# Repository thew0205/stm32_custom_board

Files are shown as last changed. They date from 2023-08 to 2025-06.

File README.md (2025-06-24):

# 🛠️ Custom STM32 Development Board

This project involves the design and fabrication of a **custom STM32 development board** based on the powerful **STM32F103C8T6** ARM Cortex-M3 microcontroller.

---

## 📷 Project Images

<div align="center">
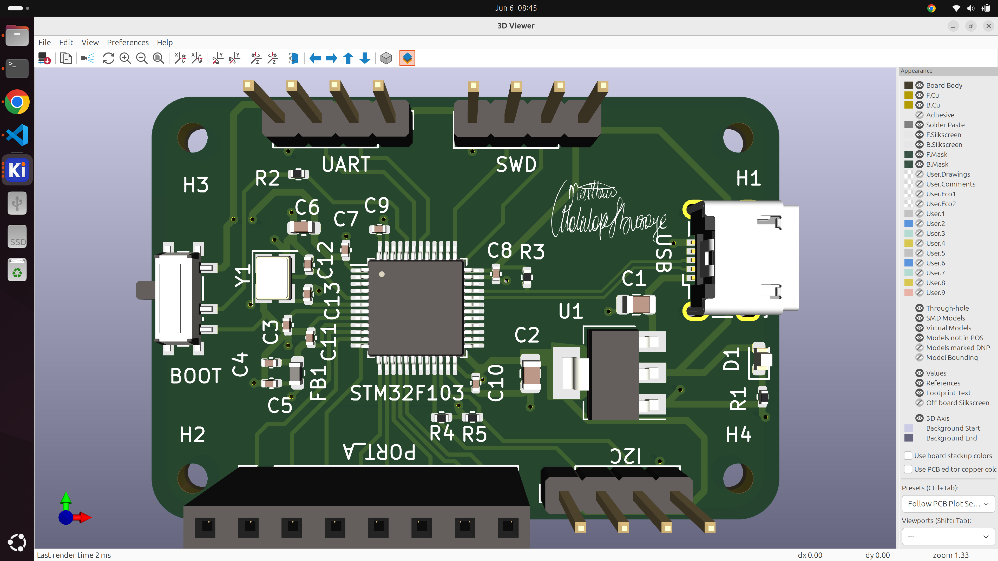
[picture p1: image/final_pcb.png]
Final PCB Layout
  
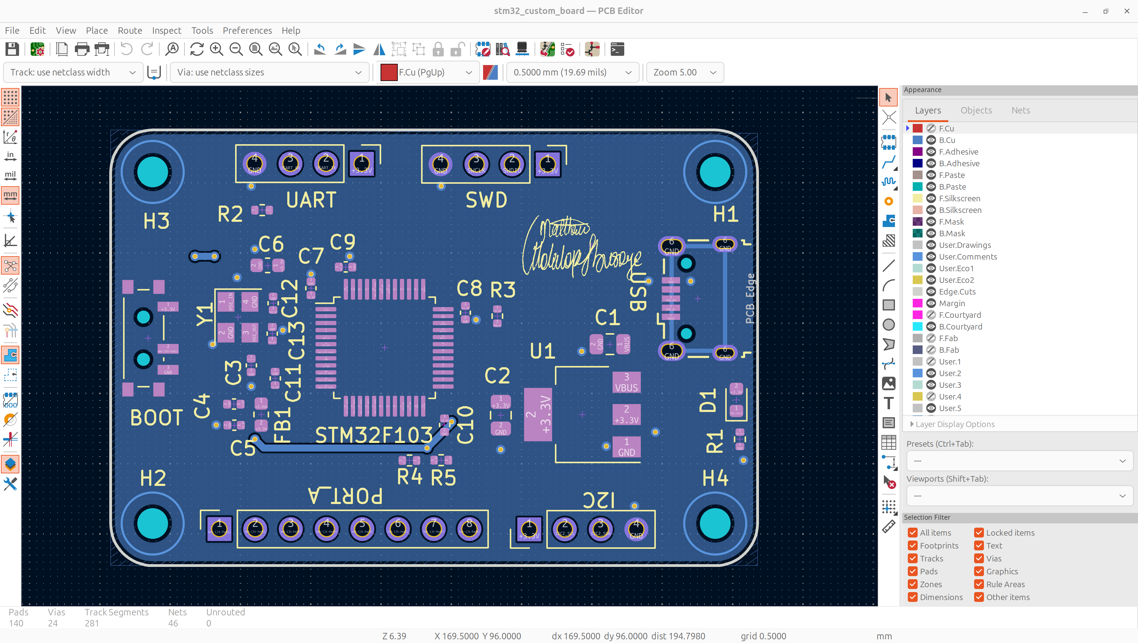
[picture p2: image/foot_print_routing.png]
Footprint Routing
  
</div>

---

## 🔧 Features

This custom board was designed from scratch to expose essential microcontroller capabilities while keeping the design compact and beginner-friendly.

- ✅ **Power Supply via USB**  
  – Provides both 5V power and USB 2.0 data communication

- 🔌 **Communication Interfaces (Breakouts)**  
  – UART  
  – I2C  

- ⚡ **GPIO Pin Breakouts**  
  – Full access to STM32 GPIOs  
  – Breadboard-friendly layout

---

## 📦 Tools and Technologies Used

- **KiCad** – Schematic & PCB design
- **STM32CubeProgrammer** – Flashing and testing
- **ST-Link v2** – SWD programming and debugging

---

## 🚀 Current Progress

- ✅ First prototype designed, routed, and fabricated
- ⚠️ Encountered soldering challenges during assembly
- 🔜 Second version planned with pre-soldered SMD components

---

## 🔬 What I Learned

- Hands-on STM32 microcontroller design
- USB data and power routing
- Communication protocol pinout handling
- Footprint selection and PCB layout best practices
- Hardware debugging and iterative prototyping

---

## 📁 Repository Contents

| File/Folder | Description |
|---|---|
| `stm32_custom_board.kicad_pcb` | PCB layout file |
| `stm32_custom_board.kicad_sch` | Circuit schematic |
| `629105150521 (rev1).stp` | 3D model of the board |
| `image/` | PCB and prototype images |
| `.gitignore` | Git ignored files |
| `README.md` | Project documentation |

---

## 👤 Author

**Busoye Tolulope Matthew**  
Final Year Electrical & Electronic Engineering Student, University of Ibadan  
💡 Passionate about embedded systems, PCB design, and low-level programming.

- 🔗 [GitHub](https://github.com/thew0205)  
- 🔗 [LinkedIn](https://linkedin.com/in/busoye-tolulope-matthew)

---

## 📜 License

This project is open-source.  
Feel free to fork, build, and improve. Consider adding a license (e.g., MIT or CERN OHL) for clarity.

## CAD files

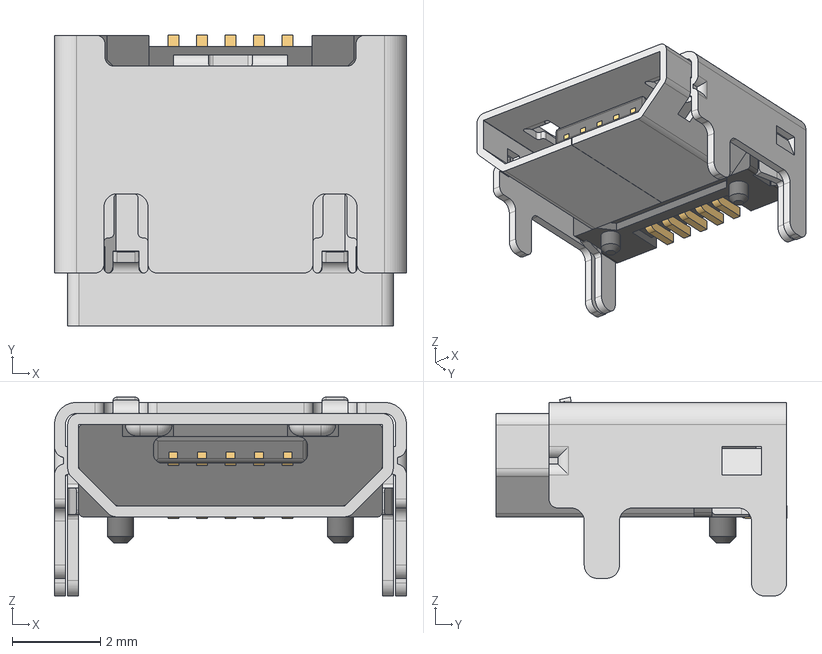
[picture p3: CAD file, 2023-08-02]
629105150521 (rev1).stp
8.00 x 6.60 x 4.52 mm
629105150521_Housing
629105150521_Pin1 x 4
629105150521_Pin2
629105150521_Shielding2
629105150521_Shielding

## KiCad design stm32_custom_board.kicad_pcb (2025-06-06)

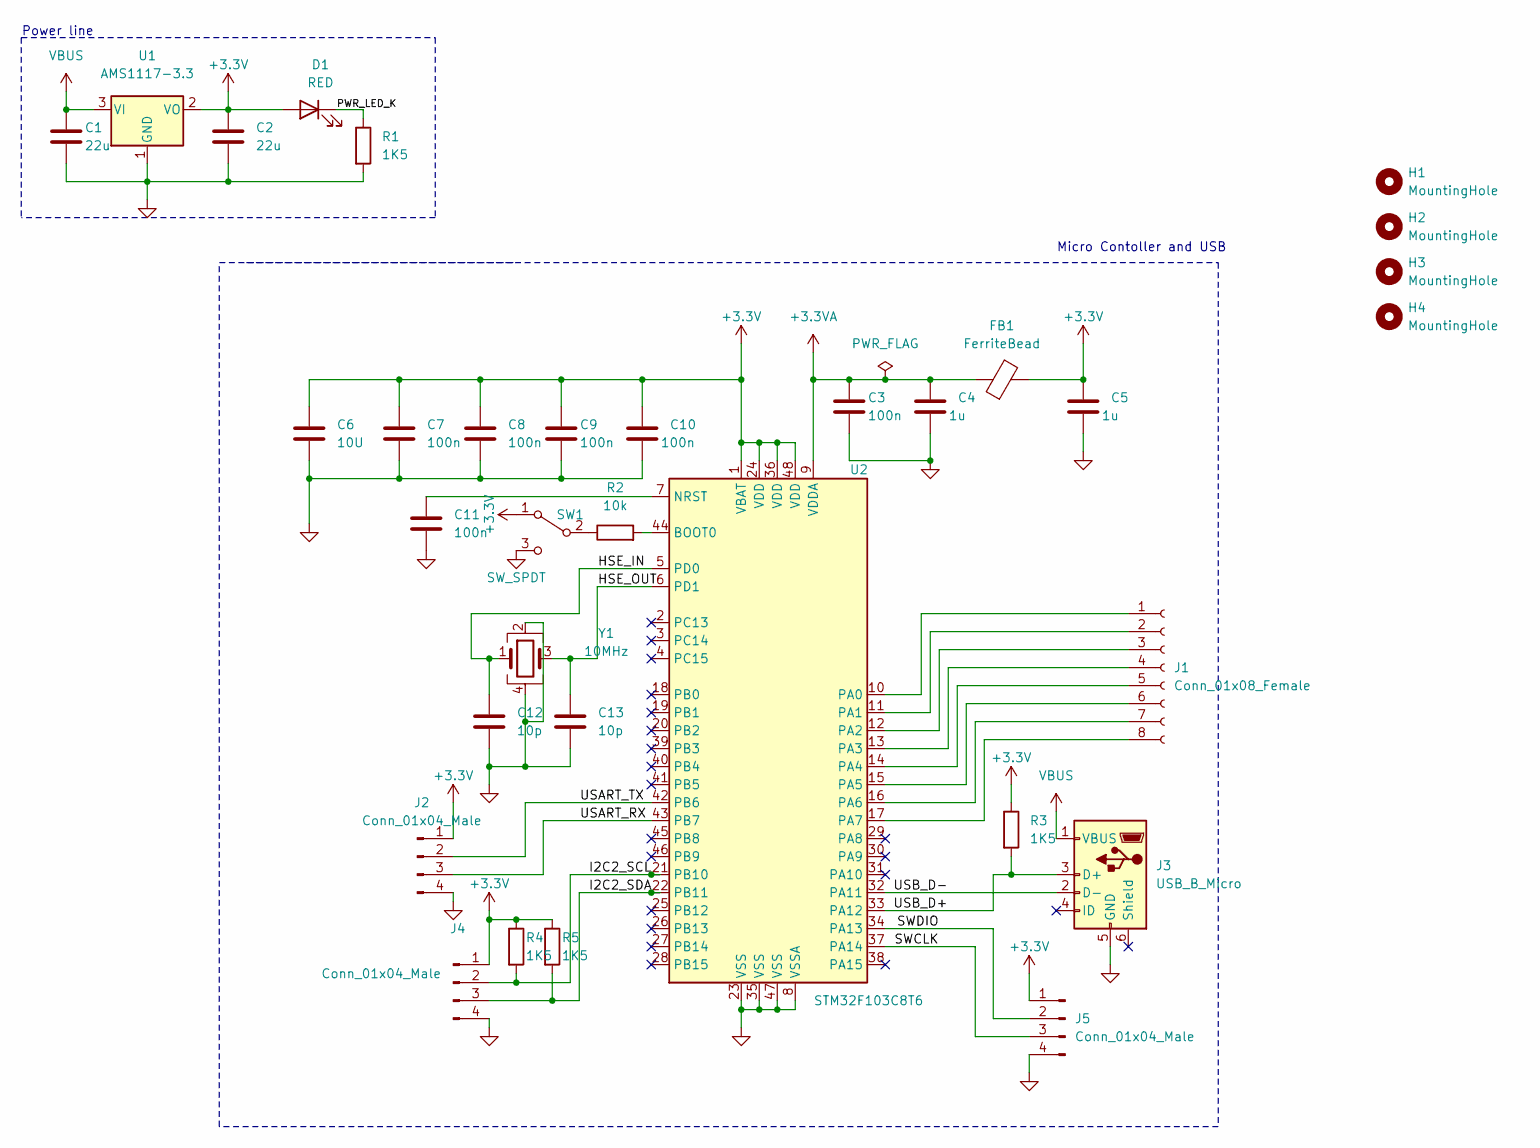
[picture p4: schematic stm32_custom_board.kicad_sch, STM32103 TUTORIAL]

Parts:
C1, C2: 22u; C_0805_2012Metric
C3, C7, C8, C9, C10, C11: 100n; C_0402_1005Metric
C4, C5: 1u; C_0402_1005Metric
C6: 10U; C_0603_1608Metric
C12, C13: 10p; C_0402_1005Metric
D1: RED; LED_0603_1608Metric
FB1: FerriteBead; L_0603_1608Metric
H1, H2, H3, H4: MountingHole; MountingHole_2.2mm_M2
J1: Conn_01x08_Female; PinSocket_1x08_P2.54mm_Vertical
J2, J4, J5: Conn_01x04_Male; PinHeader_1x04_P2.54mm_Vertical
J3: USB_B_Micro; USB_Micro-B_Wuerth_629105150521
R1, R3, R4, R5: 1K5; R_0402_1005Metric
R2: 10k; R_0402_1005Metric
SW1: SW_SPDT; SW_SPDT_PCM12
U1: AMS1117-3.3; SOT-223-3_TabPin2
U2: STM32F103C8T6; LQFP-48_7x7mm_P0.5mm
Y1: 10MHz; Crystal_SMD_3225-4Pin_3.2x2.5mm

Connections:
+3.3V: C2.1, C5.1, C6.1, C7.1, C8.1, C9.1, C10.1, D1.2 (A), FB1.2, J2.1, J4.1, J5.1, R3.1, R4.1, R5.1, SW1.1 (A), U1.2 (VO), U2.1 (VBAT), U2.24 (VDD), U2.36 (VDD), U2.48 (VDD)
+3.3VA: C3.1, C4.1, FB1.1, U2.9 (VDDA)
/HSE_IN: C12.1, U2.5 (PD0), Y1.1
/HSE_OUT: C13.1, U2.6 (PD1), Y1.3
/I2C2_SCL: J4.2, R4.2, U2.21 (PB10)
/I2C2_SDA: J4.3, R5.2, U2.22 (PB11)
/PWR_LED_K: D1.1 (K), R1.1
/SWCLK: J5.3, U2.37 (PA14)
/SWDIO: J5.2, U2.34 (PA13)
/USART_RX: J2.3, U2.43 (PB7)
/USART_TX: J2.2, U2.42 (PB6)
/USB_D+: J3.3 (D+), R3.2, U2.33 (PA12)
/USB_D-: J3.2 (D-), U2.32 (PA11)
GND: C1.2, C2.2, C3.2, C4.2, C5.2, C6.2, C7.2, C8.2, C9.2, C10.2, C11.2, C12.2, C13.2, J2.4, J3.5 (GND), J3.6 (Shield), J4.4, J5.4, R1.2, SW1.3 (C), U1.1 (GND), U2.8 (VSSA), U2.23 (VSS), U2.35 (VSS), U2.47 (VSS), Y1.2, Y1.4
unnamed: C11.1, U2.7 (NRST)
unnamed: J1.1, U2.10 (PA0)
unnamed: J1.2, U2.11 (PA1)
unnamed: J1.3, U2.12 (PA2)
unnamed: J1.4, U2.13 (PA3)
unnamed: J1.5, U2.14 (PA4)
unnamed: J1.6, U2.15 (PA5)
unnamed: J1.7, U2.16 (PA6)
unnamed: J1.8, U2.17 (PA7)
unnamed: R2.1, SW1.2 (B)
unnamed: R2.2, U2.44 (BOOT0)
VBUS: C1.1, J3.1 (VBUS), U1.3 (VI)

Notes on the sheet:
Micro Contoller and USB
Power line

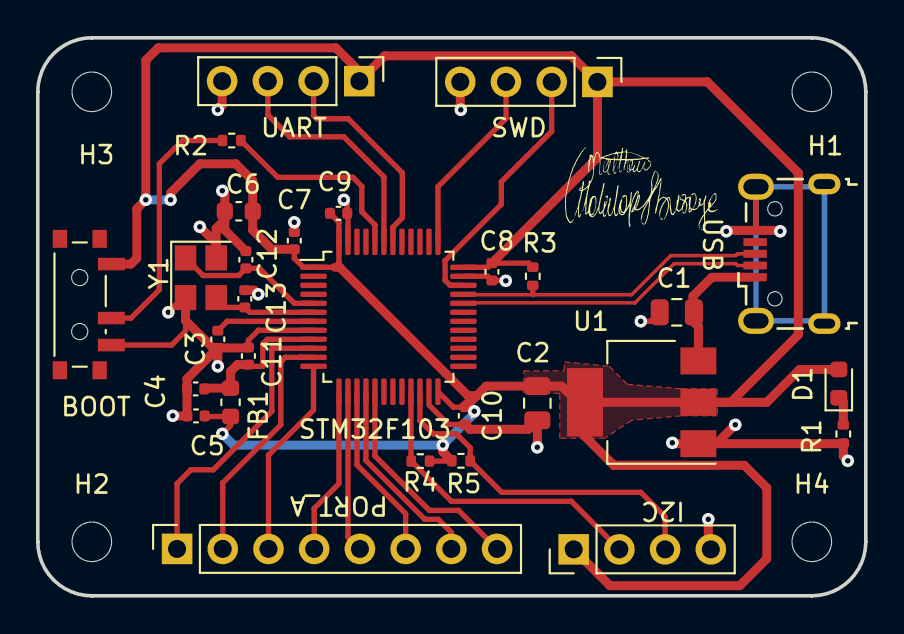
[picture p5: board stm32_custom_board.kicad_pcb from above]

Board: 2 copper layers, 46.0 x 31.0 mm, 33 parts (0 on the bottom side), 26 nets.

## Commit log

2023-08-02 Adding frist prototype file
    [629105150521 (rev1).stp, stm32_custom_board.kicad_pcb, stm32_custom_board.kicad_sch]
2025-06-06 added a gitignore file
    [stm32_custom_board.kicad_pcb, stm32_custom_board.kicad_sch]
2025-06-06 remove unnecessary traced files
2025-06-06 remove unnecessary traced filesg
